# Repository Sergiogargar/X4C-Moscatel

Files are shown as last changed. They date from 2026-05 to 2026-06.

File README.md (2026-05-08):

# X4C-Moscatel — Firmware ESP32

Nodo IoT de borde para monitorización de infraestructura ferroviaria.  
Captura la firma vibratoria del tren mediante el IMU ICM-20948, la geolocaliza
con el GPS NEO-6M y publica los datos en tiempo real vía MQTT para alimentar
el dashboard de visualización.

---

## Puesta en marcha

### Requisitos previos

- [ESP-IDF](https://docs.espressif.com/projects/esp-idf/en/latest/esp32s3/get-started/) v5.x instalado y configurado
- Docker + Docker Compose (para el backend)
- El ESP32-S3 conectado por USB

---

### Paso 1 — Obtener la IP del host

El ESP32 publica los datos MQTT al host donde corre Docker.
Antes de compilar, averigua su IP (deben estar en la misma red WiFi):

```bash
# Windows
ipconfig

# Mac / Linux
ifconfig   # o: ip route get 1 | awk '{print $7}'
```

---

### Paso 2 — Configurar el firmware

Abre **`codeina/train_digital_twin/main/network_task.cpp`** y rellena las
macros al inicio del archivo:

```c
// ─── CONFIGURAR ANTES DE FLASHEAR ────────────────────────────────
#define WIFI_SSID       "NOMBRE_DE_TU_RED"        // ← SSID de tu red WiFi
#define WIFI_PASS       "CONTRASEÑA_DE_TU_RED"    // ← Contraseña WiFi
#define MQTT_BROKER_URI "mqtt://192.168.X.X:1883" // ← IP del host del paso 1
#define TRAIN_ID        "T-101"  // ← ID único por unidad (T-101, T-102, ...)
```

> Si tienes varios ESP32, cada uno debe tener un `TRAIN_ID` distinto.

---

### Paso 3 — Arrancar el backend Docker

```bash
cd codeina/train_digital_twin/backend
docker-compose up -d
```

Comprueba que los cuatro contenedores están corriendo:

```bash
docker-compose ps
```

| Servicio | Puerto | Descripción |
|---|---|---|
| Mosquitto | `1883` | Broker MQTT. Recibe los mensajes del ESP32 |
| InfluxDB 2.7 | `8086` | Base de datos. Panel en http://localhost:8086 (`admin` / `adminpassword`) |
| Telegraf | — | Lee el topic MQTT y escribe en InfluxDB |
| Grafana | `3000` | Visualización alternativa en http://localhost:3000 (`admin` / `admin`) |

---

### Paso 4 — Compilar y flashear

```bash
cd codeina/train_digital_twin
idf.py build
idf.py flash
idf.py monitor    # muestra logs serie para verificar conexión WiFi y MQTT
```

O en un solo comando:

```bash
idf.py build flash monitor
```

---

### Paso 5 — Verificar que los datos llegan

Con `idf.py monitor` activo, deberías ver en los logs:

```
I (xxxx) NETWORK_TASK: MQTT Conectado
I (xxxx) NETWORK_TASK: Inicializando Network Task en Core 0
```

Para confirmar que los datos llegan a InfluxDB, abre http://localhost:8086,
entra con `admin` / `adminpassword`, ve a **Data Explorer** y consulta el
bucket `vibrations`. Si hay filas, el pipeline completo funciona.

---

### Referencia rápida de configuración

| Qué cambiar | Archivo | Dónde |
|---|---|---|
| Red WiFi y contraseña | `main/network_task.cpp` | Macros `WIFI_SSID` / `WIFI_PASS` |
| IP del broker MQTT | `main/network_task.cpp` | Macro `MQTT_BROKER_URI` |
| ID del tren | `main/network_task.cpp` | Macro `TRAIN_ID` |
| Umbral de impacto crítico | `main/sensor_task.cpp` | Frecuencia de muestreo y ventana FFT |
| Coordenadas de simulación GPS | `main/telemetry_task.cpp` | Función `parse_nmea()` |

---

## Estructura del firmware

```
codeina/train_digital_twin/
├── main/
│   ├── main.cpp            # Punto de entrada: crea las 4 tareas FreeRTOS
│   ├── data_types.h        # Estructuras de datos compartidas entre tareas
│   ├── telemetry_task.cpp  # Core 0: lee GPS (UART) e IMU (I2C) a 100 Hz
│   ├── sensor_task.cpp     # Core 1: muestreo ADC 10 kHz + FFT 1024 muestras
│   ├── network_task.cpp    # Core 0: WiFi + MQTT → publica JSON al broker
│   └── sd_task.cpp         # Core 0: escribe registros binarios en MicroSD
└── backend/
    ├── docker-compose.yml  # Mosquitto + InfluxDB + Telegraf + Grafana
    ├── mosquitto/config/   # Config del broker MQTT (allow_anonymous)
    └── telegraf/           # telegraf.conf: suscribe MQTT → escribe InfluxDB
```

---

## Flujo de datos

```
ICM-20948 (IMU)  ──┐
                   ├──▶  sensor_task  ──▶  FFT (1024 muestras, 10 kHz)
NEO-6M (GPS)  ─────┘         │                       │
                              │                       ▼
                        telemetry_task         dominant_freq_hz
                              │                       │
                              └───────────────────────┘
                                          │
                                    ProcessedVibrationData_t
                                    (pool de memoria, zero-copy)
                                       ┌──┴──┐
                                       ▼     ▼
                                   SD Task  Network Task
                                   (.bin)       │
                                             MQTT JSON
                                                │
                                          Mosquitto :1883
                                                │
                                           Telegraf
                                                │
                                         InfluxDB :8086
                                                │
                                         Dashboard React
```

### Payload JSON publicado

Cada mensaje MQTT al topic `train/telemetry/vibrations` tiene esta forma:

```json
{
  "timestamp":        1746700000000,
  "lat":              36.6850,
  "lon":              -6.1261,
  "alt":              55.0,
  "accel_z":          10.15,
  "dominant_freq_hz": 42.5,
  "trainId":          "T-101"
}
```

El dashboard convierte `accel_z` (m/s²) a g con `|accel_z − 9.81| / 9.81`
y clasifica el punto como ok / warning / critical según los umbrales definidos en la UI.

---

## Descripción del proyecto

Este es un GEM de Gemini con información completa del proyecto:
https://gemini.google.com/gem/1v8jnuFOj4cJeROFavsBkOiZ2vt1CeKzN?usp=sharing

El proyecto consiste en un nodo **IoT de borde (Edge Computing)** diseñado para
la monitorización de la infraestructura ferroviaria. Su función es capturar la
"firma vibratoria" y la posición geográfica del tren en tiempo real para crear
un modelo digital (Gemelo Digital) que permita predecir fallos en la vía o en
el material rodante.

**Los 3 pilares del Gemelo Digital:**

- **El Objeto Físico:** El tren y la infraestructura (vías, catenarias).
- **El Modelo Virtual:** Representación matemática — modelos de fatiga de materiales, algoritmos de predicción.
- **La Conexión de Datos (aquí entramos nosotros):** El flujo constante de información desde los sensores (ESP32-S3) hacia el modelo virtual.

**Algoritmo en el ESP32-S3:**

1. **Adquisición** — Core 1 muestrea la IMU a 10 kHz. Core 0 lee GPS a 1 Hz y gestiona escritura en SD.
2. **Fusión de datos** — Cada trama FFT se vincula al último GPS conocido mediante mutex FreeRTOS.
3. **FFT** — Ventana Hann de 1024 muestras → 512 bins de frecuencia (resolución ~9.8 Hz/bin, rango 0–5 kHz).
4. **Frecuencia dominante** — Se extrae el bin de mayor energía (ignorando DC) y se envía como `dominant_freq_hz`.
5. **Escritura segura** — SD escribe en bloques cada 100 registros para evitar corrupción ante cortes de energía.

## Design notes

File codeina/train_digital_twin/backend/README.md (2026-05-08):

# Backend de Monitorización de Vías (Gemelo Digital)

Este directorio contiene la infraestructura para recibir, almacenar y visualizar la telemetría del ESP32-S3.

## Despliegue Rápido
Asegúrate de tener instalado **Docker** y **Docker Compose**.
1. En esta misma carpeta, ejecuta:
   ```bash
   docker-compose up -d
   ```
2. Esto levantará:
   - **Mosquitto (Broker MQTT)**: Puerto 1883
   - **InfluxDB (Base de datos Time-Series)**: Puerto 8086
   - **Telegraf (Agente)**: Conecta Mosquitto con InfluxDB.
   - **Grafana (Dashboards)**: Puerto 3000

## Credenciales por Defecto
- **InfluxDB**: `admin` / `adminpassword` (Token: `my-super-secret-auth-token`)
- **Grafana**: `admin` / `admin`

## Configuración en Grafana y Consultas (Flux)

Para visualizar los datos en un panel **Geomap** de Grafana y destacar puntos donde la vibración (ej. el pico en Z o frecuencias de la FFT) supera un umbral anómalo:

1. Añade InfluxDB como Data Source en Grafana. Selecciona el lenguaje **Flux**.
2. URL: `http://influxdb:8086`, Organization: `train_org`, Token: `my-super-secret-auth-token`, Default Bucket: `vibrations`.

### Query Flux para el Mapa (Anomalías)
Asumiendo que Telegraf inserta la latitud (`lat`), longitud (`lon`), y la aceleración en Z (`accel_z`), podemos filtrar las aceleraciones que representen impactos severos (ej. baches en la vía).

```flux
from(bucket: "vibrations")
  |> range(start: v.timeRangeStart, stop: v.timeRangeStop)
  |> filter(fn: (r) => r["_measurement"] == "mqtt_consumer")
  |> filter(fn: (r) => r["_field"] == "lat" or r["_field"] == "lon" or r["_field"] == "accel_z")
  |> pivot(rowKey:["_time"], columnKey: ["_field"], valueColumn: "_value")
  // Filtrar solo vibraciones anómalas (ejemplo: aceleración Z > 12.0 m/s^2)
  |> filter(fn: (r) => r["accel_z"] > 12.0)
  |> keep(columns: ["_time", "lat", "lon", "accel_z"])
```

En Grafana, en las opciones del panel **Geomap**:
- Location: `Coords`
- Latitude field: `lat`
- Longitude field: `lon`
- Puedes usar `accel_z` para determinar el tamaño o color del marcador (ej. un marcador rojo intenso para picos grandes).

### Analizando la FFT
El espectro FFT se envía como un array JSON. InfluxDB (vía Telegraf) guardará cada índice de frecuencia si se configura correctamente o si se envían como métricas separadas en el ESP32. Para visualización avanzada de la FFT, se recomienda un panel **Bar Gauge** o **Time Series** mostrando la magnitud de frecuencias clave (ej. frecuencia de resonancia de los bogies).

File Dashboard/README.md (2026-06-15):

# Xerez4Change — Dashboard

Dashboard de monitorización de vibraciones en vía férrea.  
Visualiza en tiempo real los puntos GPS enviados por el ESP32, con código de colores por nivel de vibración, filtros por fecha/tren/anomalía y diseño en modo oscuro.

---

## Configuración y arranque

### Requisitos previos

- Node.js ≥ 18
- El backend Docker arrancado (ver sección [Backend](#backend))

### 1. Instalar dependencias

```bash
cd Xerez4Change-Dashboard
npm install
```

### 2. Configurar la conexión a InfluxDB

Edita el archivo **`.env`** en la raíz del proyecto. Los valores por defecto
corresponden a la configuración estándar del `docker-compose` del backend:

```env
VITE_INFLUX_TOKEN=my-super-secret-auth-token
VITE_INFLUX_ORG=train_org
VITE_INFLUX_BUCKET=vibrations
VITE_POLL_INTERVAL_MS=10000
```

> En desarrollo, las peticiones a InfluxDB van a través del proxy de Vite
> (`/influx → http://localhost:8086`), por lo que no hace falta exponer la URL.  
> Para producción, añade `VITE_INFLUX_URL=http://<ip-servidor>:8086`.

### 3. Arrancar el servidor de desarrollo

```bash
npm run dev
```

El dashboard estará disponible en **http://localhost:5173**.

Si InfluxDB no está arrancado, el dashboard carga automáticamente datos de
demostración (mock) y muestra el indicador **"Simulado · Mock"** en la cabecera.
En cuanto el backend esté activo y con datos, cambia a **"En vivo · InfluxDB"**.

### 4. Compilar para producción

```bash
npm run build      # genera dist/
npm run preview    # sirve el build en http://localhost:4173
```

---

## Backend

El backend vive en `X4C-Moscatel/codeina/train_digital_twin/backend/`.

### 1. Averiguar la IP de tu máquina

El ESP32 necesita saber a qué IP conectarse. Antes de flashear, obtén la IP
del host donde vas a correr Docker y anótala:

```bash
# Windows
ipconfig
# Mac / Linux
ifconfig   # o: ip route get 1 | awk '{print $7}'
```

> El ESP32 y el host deben estar en la **misma red WiFi**.

### 2. Arrancar el backend Docker

```bash
cd X4C-Moscatel/codeina/train_digital_twin/backend
docker-compose up -d
```

Levanta cuatro servicios:

| Servicio | Puerto | Descripción |
|---|---|---|
| Mosquitto | `1883` | Broker MQTT. Recibe los mensajes del ESP32 |
| InfluxDB 2.7 | `8086` | Base de datos de series temporales. Panel en http://localhost:8086 (`admin` / `adminpassword`) |
| Telegraf | — | Suscribe el topic MQTT y escribe los campos en InfluxDB |
| Grafana | `3000` | Dashboard alternativo en http://localhost:3000 (`admin` / `admin`) |

Para verificar que los contenedores están corriendo:

```bash
docker-compose ps
```

### 3. Configurar y flashear el ESP32

Antes de flashear, edita **`X4C-Moscatel/codeina/train_digital_twin/main/network_task.cpp`**
y rellena las tres macros al inicio del archivo:

```c
#define WIFI_SSID       "NOMBRE_DE_TU_RED"        // ← tu red WiFi
#define WIFI_PASS       "CONTRASEÑA_DE_TU_RED"    // ← tu contraseña
#define MQTT_BROKER_URI "mqtt://192.168.X.X:1883" // ← IP del host del paso 1
#define TRAIN_ID        "T-101"                   // ← ID único por unidad
```

Luego compila y flashea con ESP-IDF:

```bash
cd X4C-Moscatel/codeina/train_digital_twin
idf.py build flash monitor
```

Una vez el ESP32 esté corriendo y con fix GPS, los puntos empezarán a
aparecer en el mapa con el indicador **"En vivo · InfluxDB"** en la cabecera.

---

## Cómo funciona

### Flujo completo de datos

```
ESP32 (WiFi + MQTT)
    │  topic: train/telemetry/vibrations
    ▼
Mosquitto :1883
    │
    ▼
Telegraf  →  aplana JSON  →  InfluxDB :8086
                                    │
                                    │  Flux query (cada 10 s)
                                    ▼
                            geoService.ts
                                    │  parseInfluxCSV()
                                    │  accel_z → vibration_g
                                    │  deriva anomalyType
                                    ▼
                            useGeoData.ts  →  dashboardStore.ts
                                                    │
                                    ┌───────────────┘
                                    │  filteredPoints
                                    ▼
                            GeoMap.tsx  →  CircleMarker por cada punto
```

### Lógica interna capa a capa

#### `src/services/geoService.ts` — Origen de datos

Es el único punto de entrada de datos al dashboard. Ejecuta una consulta Flux
sobre InfluxDB pidiendo las últimas 2 horas de mediciones, máximo 500 puntos:

```flux
from(bucket: "vibrations")
  |> range(start: -2h)
  |> filter(fn: (r) => r._measurement == "mqtt_consumer")
  |> pivot(rowKey:["_time"], columnKey: ["_field"], valueColumn: "_value")
  |> sort(columns: ["_time"], desc: false)
  |> limit(n: 500)
```

La respuesta es un CSV anotado (formato nativo de InfluxDB v2). El parser
interno lo convierte línea a línea en objetos `GeoPoint`:

- `lat`, `lon` → coordenadas directas
- `accel_z` (m/s²) → `vibration` en g: `|accel_z − 9.81| / 9.81`
- `trainId` → identificador del tren
- `_time` → timestamp ISO
- `dominant_freq_hz` → campo opcional si el ESP32 lo calcula y envía

Si InfluxDB no responde o devuelve datos vacíos, la función cae silenciosamente
a los datos mock y el indicador de cabecera cambia de verde a ámbar.
El módulo expone `getLastSource()` para que el hook sepa qué fuente se usó.

#### `src/utils/vibration.ts` — Clasificación y colores

Toda la lógica de semáforo está centralizada aquí. Los umbrales son:

| Vibración | Nivel | Color | Radio del marcador |
|---|---|---|---|
| < 0.3 g | `ok` | Verde `#10b981` | 6 px |
| 0.3 – 0.7 g | `warning` | Ámbar `#f59e0b` | 9 px |
| ≥ 0.7 g | `critical` | Rojo `#ef4444` | 12 px |

Para ajustar cuándo se considera crítico un punto, edita las constantes
`THRESHOLDS.warning` y `THRESHOLDS.critical` en este archivo.  
El campo `level` del tipo `GeoPoint` siempre se calcula aquí; los datos
de entrada no necesitan incluirlo.

#### `src/hooks/useGeoData.ts` — Ciclo de refresco

Al montarse, lanza la primera carga (con spinner) y arranca un `setInterval`
que refresca los datos cada `VITE_POLL_INTERVAL_MS` milisegundos (10 s por defecto).
Los refrescos periódicos son silenciosos: el mapa se actualiza sin parpadear.
Al desmontar el componente, cancela el intervalo y marca las peticiones en vuelo
como descartadas para evitar actualizar estado de componentes ya desmontados.

#### `src/store/dashboardStore.ts` — Estado global (Zustand)

Almacén central con dos listas de puntos:

- `points` — todos los puntos recibidos, sin filtrar
- `filteredPoints` — resultado de aplicar los filtros activos sobre `points`

Cada vez que llegan nuevos datos (`setPoints`) o cambia un filtro (`setFilters`),
`applyFilters()` recalcula `filteredPoints` en el mismo tick. El mapa solo
consume `filteredPoints`, por lo que nunca ve datos que no pasen los filtros.

Los tres filtros disponibles se evalúan en AND:

1. **Rango de fechas** — compara el `timestamp` ISO del punto con `[inicio, fin]`
2. **ID de tren** — coincidencia exacta de `trainId`
3. **Tipo de anomalía** — coincidencia exacta de `anomalyType`

#### `src/components/GeoMap.tsx` — Visualización

Componente puramente visual. Recibe `data: GeoPoint[]` y no sabe de dónde vienen.
Renderiza sobre un `MapContainer` de Leaflet centrado en la zona Jerez–Cádiz
(`[36.62, −6.20]`, zoom 12) con capa CartoDB Dark Matter.

Por cada punto crea un `CircleMarker` cuyo color y radio vienen de
`getVibrationColor()` y `getMarkerRadius()` de `vibration.ts`. Los puntos
críticos tienen borde de 2 px en lugar de 1 px para destacar más.

Cada marcador tiene:
- **Tooltip** (hover): tren + vibración, aparece rápido
- **Popup** (click): detalle completo — nivel, tren, vibración, frecuencia dominante (si existe), tipo de anomalía (si existe) y timestamp formateado

Dos overlays posicionados con `z-index: 1000` sobre el mapa:
- **`Legend`** — abajo a la izquierda, muestra los tres colores con sus rangos
- **`Stats`** — arriba a la derecha, muestra total de puntos, avisos y críticos

#### `src/components/FilterBar.tsx` — Filtros

Los desplegables de tren y anomalía se alimentan de `fetchTrainIds()` y
`fetchAnomalyTypes()`, que derivan los valores únicos de los propios datos.
Cualquier filtro que se active llama a `setFilters()` del store, lo que
recalcula `filteredPoints` al instante sin ninguna petición de red adicional.

---

## Estructura de archivos

```
src/
├── components/
│   ├── GeoMap.tsx          # Mapa Leaflet: marcadores, leyenda, stats
│   └── FilterBar.tsx       # Filtros de fecha, tren y anomalía
├── hooks/
│   └── useGeoData.ts       # Polling + carga inicial + fuente activa
├── services/
│   └── geoService.ts       # Flux query → parse CSV → GeoPoint[] (fallback mock)
├── store/
│   └── dashboardStore.ts   # Zustand: puntos, filtros, loading, error
├── utils/
│   └── vibration.ts        # Umbrales, colores, radios, formateo
├── types.ts                # GeoPoint, DashboardFilters, VibrationLevel
├── App.tsx                 # Layout: cabecera + badge de estado + mapa
├── main.tsx                # Punto de entrada de React
└── index.css               # Tailwind + estilos oscuros para popups de Leaflet
```

---

## Referencia rápida

| Necesidad | Dónde |
|---|---|
| Cambiar token / org / bucket de InfluxDB | `.env` |
| Cambiar intervalo de refresco | `.env` → `VITE_POLL_INTERVAL_MS` |
| Cambiar IP de InfluxDB en producción | `.env` → `VITE_INFLUX_URL` |
| Ajustar umbrales de vibración | `src/utils/vibration.ts` → `THRESHOLDS` |
| Cambiar ventana de tiempo de la query | `src/services/geoService.ts` → `range(start: -2h)` |
| Cambiar centro o zoom inicial del mapa | `src/components/GeoMap.tsx` → `DEFAULT_CENTER`, `DEFAULT_ZOOM` |
| Añadir un filtro nuevo | `src/types.ts` + `src/store/dashboardStore.ts` + `src/components/FilterBar.tsx` |

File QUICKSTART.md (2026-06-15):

# Guía de inicio rápido — X4C Moscatel

## Requisitos

| Herramienta | Versión mínima |
|---|---|
| ESP-IDF | v5.x |
| Docker + Docker Compose | cualquiera |
| Node.js | v18+ |
| Git | cualquiera |

---

## 1. Configurar el firmware

Abre `codeina/train_digital_twin/main/network_task.cpp` y edita las 4 macros al inicio:

```c
#define WIFI_SSID       "MI_RED_WIFI"
#define WIFI_PASS       "MI_CONTRASEÑA"
#define MQTT_BROKER_URI "mqtt://192.168.X.X:1883"   // IP del PC donde corre Docker
#define TRAIN_ID        "T-101"
```

Para saber la IP del PC: `ipconfig` (Windows) o `ip a` (Linux/Mac).

---

## 2. Arrancar el backend Docker

```bash
cd codeina/train_digital_twin/backend
docker-compose up -d
```

Comprueba que los 4 contenedores están en "Up":

```bash
docker-compose ps
```

| Servicio | URL | Credenciales |
|---|---|---|
| InfluxDB | http://localhost:8086 | admin / adminpassword |
| Grafana | http://localhost:3000 | admin / admin |
| Mosquitto (MQTT) | localhost:1883 | sin autenticación |
| Telegraf | — | puente interno |

---

## 3. Flashear el ESP32

```bash
cd codeina/train_digital_twin
idf.py build flash monitor
```

En el monitor serie deberías ver:

```
I (xxx) MAIN: Iniciando Gemelo Digital de Tren
I (xxx) NETWORK_TASK: WiFi conectado. IP asignada: 192.168.X.X
I (xxx) NETWORK_TASK: MQTT Conectado
I (xxx) SENSOR_TASK: Dato Crudo Z: X.XX m/s2 | Freq Dominante: XX.XX Hz
```

---

## 4. Arrancar el dashboard

```bash
cd Dashboard
npm install
npm run dev
```

Abre http://localhost:5173

- Indicador **verde "En vivo · InfluxDB"** → datos reales del ESP32
- Indicador **ámbar "Simulado · Mock"** → InfluxDB no accesible (revisa paso 2)

---

## Verificar que el pipeline completo funciona

### A. InfluxDB recibe datos
1. Entra en http://localhost:8086 → `admin / adminpassword`
2. Ve a **Data Explorer** → bucket `vibrations`
3. Selecciona measurement `mqtt_consumer` → deberías ver campos: `lat`, `lon`, `accel_z`, `dominant_freq_hz`

### B. Dashboard muestra datos en el mapa
- Los marcadores aparecen en la zona Jerez–Cádiz (lat ~36.6, lon ~-6.1)
- **Verde** = vibración < 0.3 g (normal)
- **Ámbar** = vibración 0.3–0.7 g (aviso)
- **Rojo** = vibración > 0.7 g (crítico)
- Haz clic en un marcador para ver: tren, vibración, frecuencia dominante, timestamp

### C. MQTT llega al broker
```bash
# Instalar mosquitto-clients si no lo tienes
docker exec mqtt_broker mosquitto_sub -t "train/telemetry/vibrations" -v
```
Deberías ver mensajes JSON como:
```json
{"timestamp":1234567890000,"lat":36.685,"lon":-6.126,"accel_z":9.95,"dominant_freq_hz":42.5,"trainId":"T-101"}
```

---

## Formato del payload MQTT

El ESP32 publica en el topic `train/telemetry/vibrations`:

```json
{
  "timestamp":        1746700000000,
  "lat":              36.6850,
  "lon":             -6.1261,
  "alt":              55.0,
  "accel_z":          9.95,
  "dominant_freq_hz": 42.5,
  "vibration_amp":    -12.3,
  "trainId":          "T-101"
}
```

El dashboard convierte `accel_z` (m/s²) a g con `|accel_z − 9.81| / 9.81`.

> **Nota:** El ESP32 descarta automáticamente los puntos sin fix GPS para no publicar coordenadas (0, 0).

---

## Parar todo

```bash
# Backend
cd codeina/train_digital_twin/backend
docker-compose down

# Dashboard: Ctrl+C en la terminal
```

---

## Problemas frecuentes

| Síntoma | Causa probable | Solución |
|---|---|---|
| Dashboard en modo mock (ámbar) | Backend no arrancado o InfluxDB sin datos | Ejecutar paso 2, esperar 30 s y recargar |
| Monitor serie: `Conexion WiFi fallida` | SSID/contraseña incorrectos | Revisar macros en `network_task.cpp` y reflashear |
| Monitor serie: `GPS sin fix` | Módulo GPS sin señal (normal en interiores) | Llevar el dispositivo al exterior; los datos no se publican hasta obtener fix |
| `docker-compose ps` muestra contenedores en "Exit" | Puerto 8086 o 1883 ocupado por otra app | `docker-compose logs <servicio>` para ver el error |
| Mapa vacío pese a datos en InfluxDB | El query Flux filtra `-2h`; datos más antiguos no aparecen | Comprobar que el reloj del ESP32 y el host están sincronizados |

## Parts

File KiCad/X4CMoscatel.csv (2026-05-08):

Reference | Qty | Value | DNP | Exclude from BOM | Exclude from Board | Footprint | Datasheet
C1,C3,C4,C5 | 4 | 100nF |  |  |  | Capacitor_SMD:C_0805_2012Metric | ~
C2 | 1 | 10microF |  |  |  | Capacitor_SMD:C_0805_2012Metric | ~
D1 | 1 | D_Schottky |  |  |  | Diode_SMD:D_SMA | ~
D2,D3 | 2 | LED |  |  |  | LED_SMD:LED_0805_2012Metric | ~
D4 | 1 | BAT54S |  |  |  | Package_TO_SOT_SMD:SOT-23 | https://www.diodes.com/assets/Datasheets/ds11005.pdf
H1,H3,H4 | 3 | MountingHole |  | Excluido del BOM |  | MountingHole:MountingHole_3.2mm_M3 | ~
J1 | 1 | Conn_01x04 |  |  |  | Connector_PinHeader_2.54mm:PinHeader_1x04_P2.54mm_Vertical | ~
J2 | 1 | Micro_SD_Card_Det_Hirose_DM3AT |  |  |  | Connector_Card:microSD_HC_Molex_104031-0811 | https://www.hirose.com/product/en/download_file/key_name/DM3/category/Catalog/doc_file_id/49662/?item_id=195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
J3 | 1 | USB_C_Receptacle_USB2.0_14P |  |  |  | Connector_USB:USB_C_Receptacle_HRO_TYPE-C-31-M-12 | https://www.usb.org/sites/default/files/documents/usb_type-c.zip
J4 | 1 | Conn_01x02_Pin |  |  |  | Connector_JST:JST_PH_S2B-PH-K_1x02_P2.00mm_Horizontal | ~
J5 | 1 | Conn_01x10_Pin |  |  |  | Connector_PinHeader_2.54mm:PinHeader_1x10_P2.54mm_Vertical | ~
J6 | 1 | Conn_01x02_Pin |  |  |  | Connector_PinSocket_2.54mm:PinSocket_1x02_P2.54mm_Vertical | ~
R1,R3 | 2 | 10k |  |  |  | Resistor_SMD:R_0805_2012Metric | ~
R2,R7 | 2 | 5.1k |  |  |  | Resistor_SMD:R_0805_2012Metric | ~
R4 | 1 | 2k |  |  |  | Resistor_SMD:R_0805_2012Metric | ~
R5,R6 | 2 | 1k |  |  |  | Resistor_SMD:R_0805_2012Metric | ~
R8,R9,R10 | 3 | 1M |  |  |  | Resistor_SMD:R_0805_2012Metric | ~
SW1,SW2 | 2 | SW_Push |  |  |  | Button_Switch_SMD:SW_Push_SPST_NO_Alps_SKRK | ~
SW3 | 1 | SW_Wuerth_450301014042 |  |  |  | Button_Switch_THT:SW_Slide-03_Wuerth-WS-SLTV_10x2.5x6.4_P2.54mm | https://www.we-online.com/components/products/datasheet/450301014042.pdf
U1 | 1 | ESP32-S3-WROOM-1 |  |  |  | RF_Module:ESP32-S3-WROOM-1 | https://www.espressif.com/sites/default/files/documentation/esp32-s3-wroom-1_wroom-1u_datasheet_en.pdf
U2 | 1 | MCP6002-xMC |  |  |  | Package_DFN_QFN:DFN-8-1EP_3x2mm_P0.5mm_EP1.75x1.45mm | http://ww1.microchip.com/downloads/en/DeviceDoc/21733j.pdf
U3 | 1 | LD1117V33 |  |  |  | Package_TO_SOT_THT:TO-220-3_Vertical | https://www.st.com/resource/en/datasheet/ld1117.pdf
U4 | 1 | MCP73831-2-OT |  |  |  | Package_TO_SOT_SMD:SOT-23-5 | http://ww1.microchip.com/downloads/en/DeviceDoc/20001984g.pdf

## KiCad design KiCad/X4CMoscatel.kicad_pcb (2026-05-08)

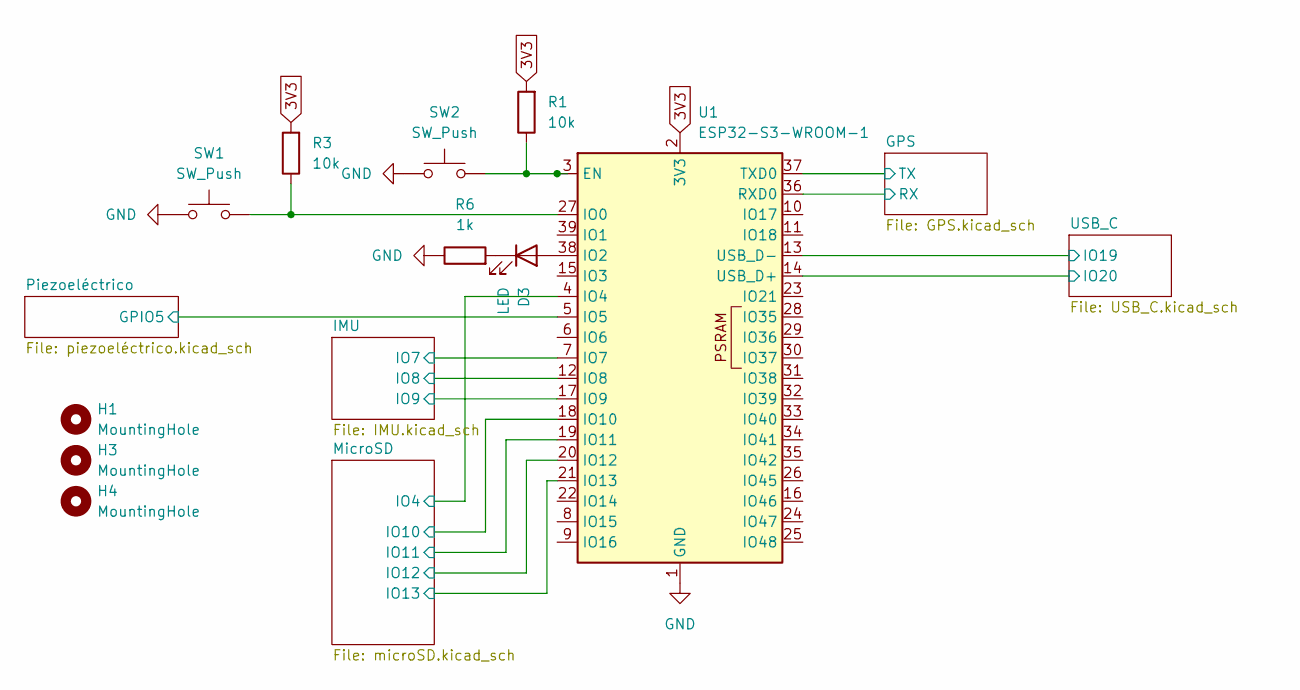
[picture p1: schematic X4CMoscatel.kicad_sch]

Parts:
D3: LED; LED_0805_2012Metric
H1, H3, H4: MountingHole; MountingHole_3.2mm_M3
R1, R3: 10k; R_0805_2012Metric
R6: 1k; R_0805_2012Metric
SW1, SW2: SW_Push; SW_Push_SPST_NO_Alps_SKRK
U1: ESP32-S3-WROOM-1

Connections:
3V3: R1.2, R3.2, U1.2 (3V3); also elsewhere on the board
/GPS/RX: U1.36 (RXD0); also elsewhere on the board
/GPS/TX: U1.37 (TXD0); also elsewhere on the board
/IMU/IO7: U1.7 (IO7); also elsewhere on the board
/IMU/IO8: U1.12 (IO8); also elsewhere on the board
/IMU/IO9: U1.17 (IO9); also elsewhere on the board
/MicroSD/IO4: U1.4 (IO4); also elsewhere on the board
/MicroSD/IO10: U1.18 (IO10); also elsewhere on the board
/MicroSD/IO11: U1.19 (IO11); also elsewhere on the board
/MicroSD/IO12: U1.20 (IO12); also elsewhere on the board
/MicroSD/IO13: U1.21 (IO13); also elsewhere on the board
/Piezoeléctrico/GPIO5: U1.5 (IO5); also elsewhere on the board
/USB_C/IO19: U1.13 (USB_D-); also elsewhere on the board
/USB_C/IO20: U1.14 (USB_D+); also elsewhere on the board
GND: R6.1, SW1.1, SW2.1, U1.1 (GND), U1.40 (GND), U1.41 (GND); also elsewhere on the board
unnamed: D3.2 (A), U1.38 (IO2)
unnamed: D3.1 (K), R6.2
unnamed: R1.1, SW2.2, U1.3 (EN)
unnamed: R3.1, SW1.2, U1.27 (IO0)

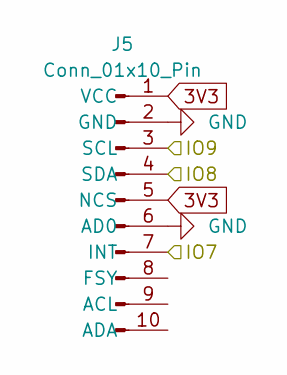
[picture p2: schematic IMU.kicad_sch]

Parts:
J5: Conn_01x10_Pin; PinHeader_1x10_P2.54mm_Vertical

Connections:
3V3: J5.1 (VCC), J5.5 (NCS); also elsewhere on the board
/IMU/IO7: J5.7 (INT); also elsewhere on the board
/IMU/IO8: J5.4 (SDA); also elsewhere on the board
/IMU/IO9: J5.3 (SCL); also elsewhere on the board
GND: J5.2 (GND), J5.6 (AD0); also elsewhere on the board

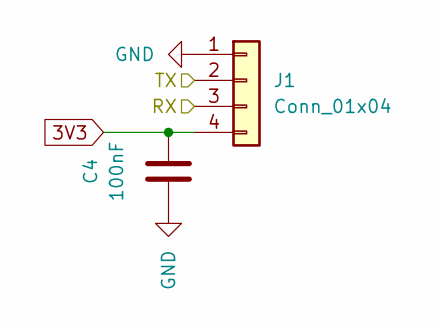
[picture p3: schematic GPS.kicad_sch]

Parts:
C4: 100nF; C_0805_2012Metric
J1: Conn_01x04; PinHeader_1x04_P2.54mm_Vertical

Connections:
3V3: C4.2, J1.4; also elsewhere on the board
/GPS/RX: J1.3; also elsewhere on the board
/GPS/TX: J1.2; also elsewhere on the board
GND: C4.1, J1.1; also elsewhere on the board

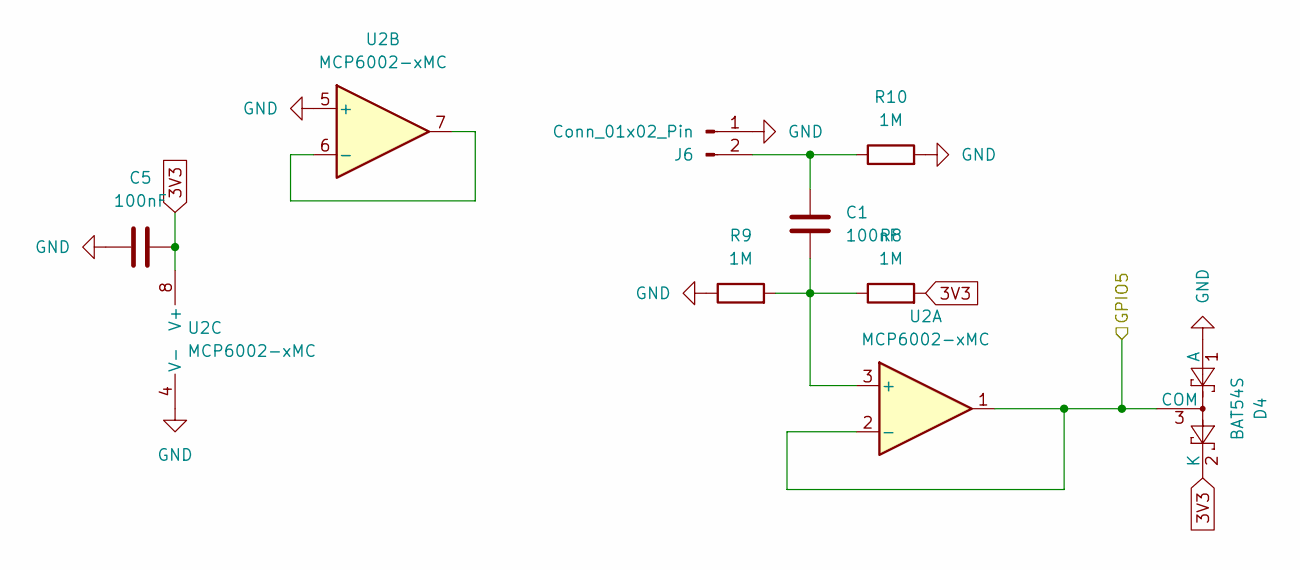
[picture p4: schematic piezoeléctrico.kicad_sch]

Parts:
C1, C5: 100nF; C_0805_2012Metric
D4: BAT54S; SOT-23
J6: Conn_01x02_Pin; PinSocket_1x02_P2.54mm_Vertical
R8, R9, R10: 1M; R_0805_2012Metric
U2: MCP6002-xMC; DFN-8-1EP_3x2mm_P0.5mm_EP1.75x1.45mm

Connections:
3V3: C5.1, D4.2 (K), R8.2, U2.8 (V+); also elsewhere on the board
/Piezoeléctrico/GPIO5: D4.3 (COM), U2.1, U2.2 (-); also elsewhere on the board
GND: C5.2, D4.1 (A), J6.1, R9.1, R10.2, U2.4 (V-), U2.5 (+), U2.9 (V-); also elsewhere on the board
unnamed: C1.2, J6.2, R10.1
unnamed: C1.1, R8.1, R9.2, U2.3 (+)
unnamed: U2.6 (-), U2.7

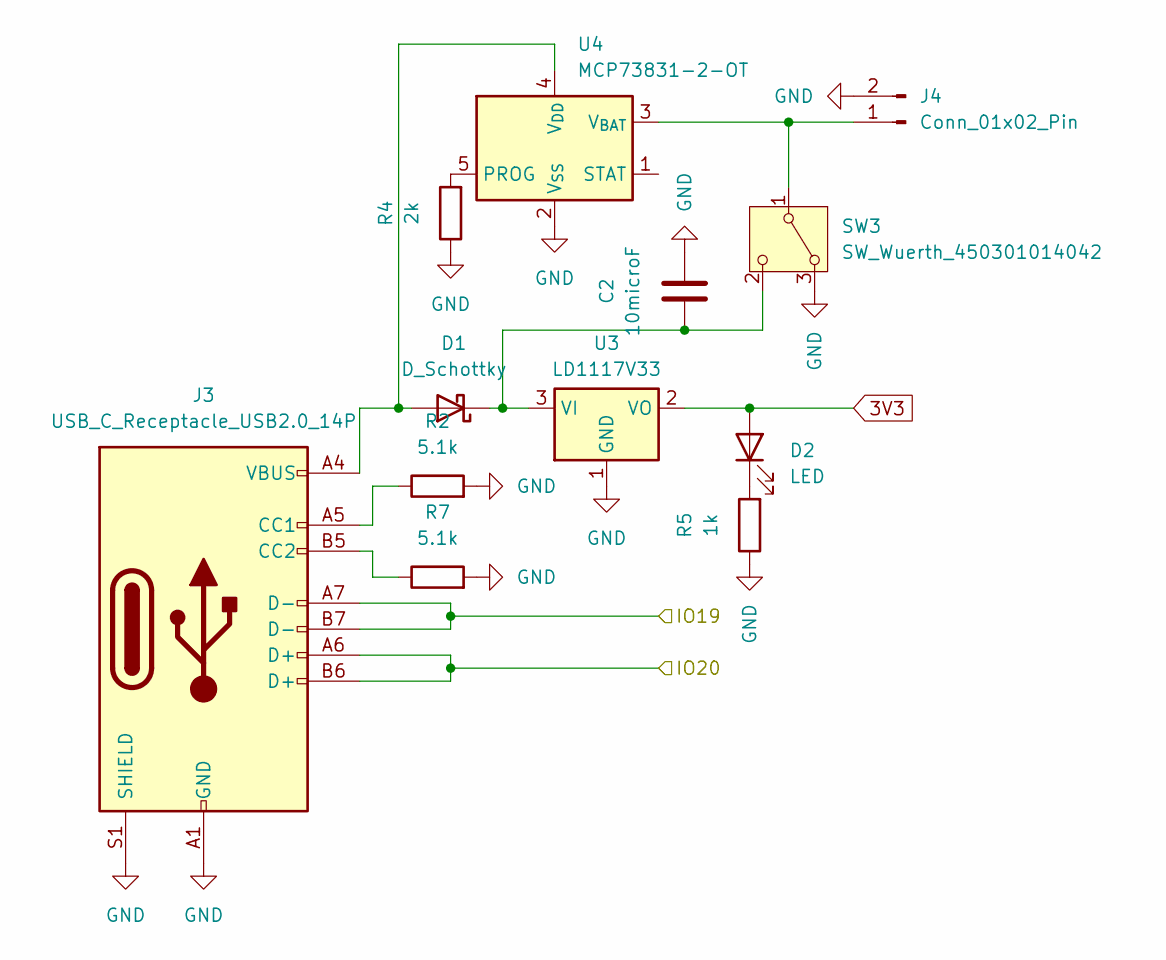
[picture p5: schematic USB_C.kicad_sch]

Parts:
C2: 10microF; C_0805_2012Metric
D1: D_Schottky; D_SMA
D2: LED; LED_0805_2012Metric
J3: USB_C_Receptacle_USB2.0_14P; USB_C_Receptacle_HRO_TYPE-C-31-M-12
J4: Conn_01x02_Pin; JST_PH_S2B-PH-K_1x02_P2.00mm_Horizontal
R2, R7: 5.1k; R_0805_2012Metric
R4: 2k; R_0805_2012Metric
R5: 1k; R_0805_2012Metric
SW3: SW_Wuerth_450301014042; SW_Slide-03_Wuerth-WS-SLTV_10x2.5x6.4_P2.54mm
U3: LD1117V33; TO-220-3_Vertical
U4: MCP73831-2-OT; SOT-23-5

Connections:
3V3: D2.2 (A), U3.2 (VO); also elsewhere on the board
/USB_C/IO19: J3.A7 (D-), J3.B7 (D-); also elsewhere on the board
/USB_C/IO20: J3.A6 (D+), J3.B6 (D+); also elsewhere on the board
GND: C2.2, J3.A1 (GND), J3.A12 (GND), J3.B1 (GND), J3.B12 (GND), J3.S1 (SHIELD), J4.2, R2.2, R4.1, R5.1, R7.2, SW3.3 (A), U3.1 (GND), U4.2 (V_{SS}); also elsewhere on the board
unnamed: D1.2 (A), J3.A4 (VBUS), J3.A9 (VBUS), J3.B4 (VBUS), J3.B9 (VBUS), U4.4 (V_{DD})
unnamed: C2.1, D1.1 (K), SW3.2 (C), U3.3 (VI)
unnamed: D2.1 (K), R5.2
unnamed: J3.A5 (CC1), R2.1
unnamed: J3.B5 (CC2), R7.1
unnamed: J4.1, SW3.1 (B), U4.3 (V_{BAT})
unnamed: R4.2, U4.5 (PROG)

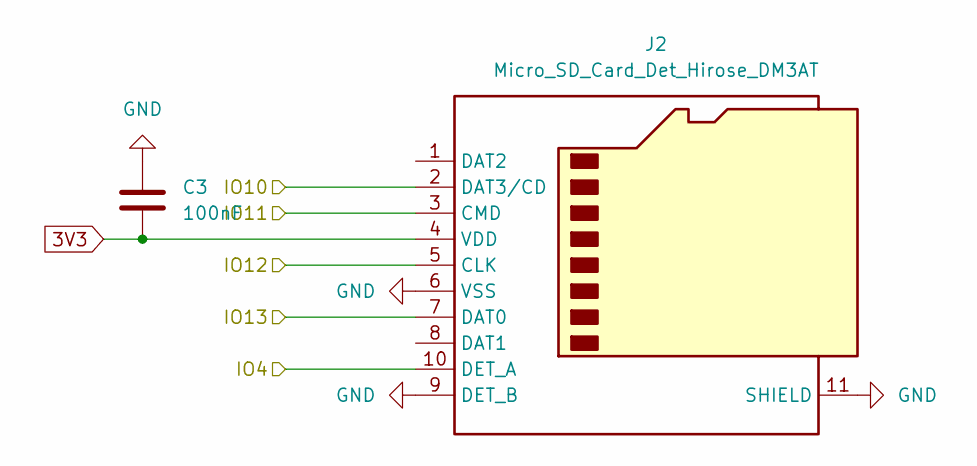
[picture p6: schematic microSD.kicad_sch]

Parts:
C3: 100nF; C_0805_2012Metric
J2: Micro_SD_Card_Det_Hirose_DM3AT; microSD_HC_Molex_104031-0811

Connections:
3V3: C3.1, J2.4 (VDD); also elsewhere on the board
/MicroSD/IO4: J2.10 (DET_A); also elsewhere on the board
/MicroSD/IO10: J2.2 (DAT3/CD); also elsewhere on the board
/MicroSD/IO11: J2.3 (CMD); also elsewhere on the board
/MicroSD/IO12: J2.5 (CLK); also elsewhere on the board
/MicroSD/IO13: J2.7 (DAT0); also elsewhere on the board
GND: C3.2, J2.6 (VSS), J2.9 (DET_B), J2.11 (SHIELD); also elsewhere on the board

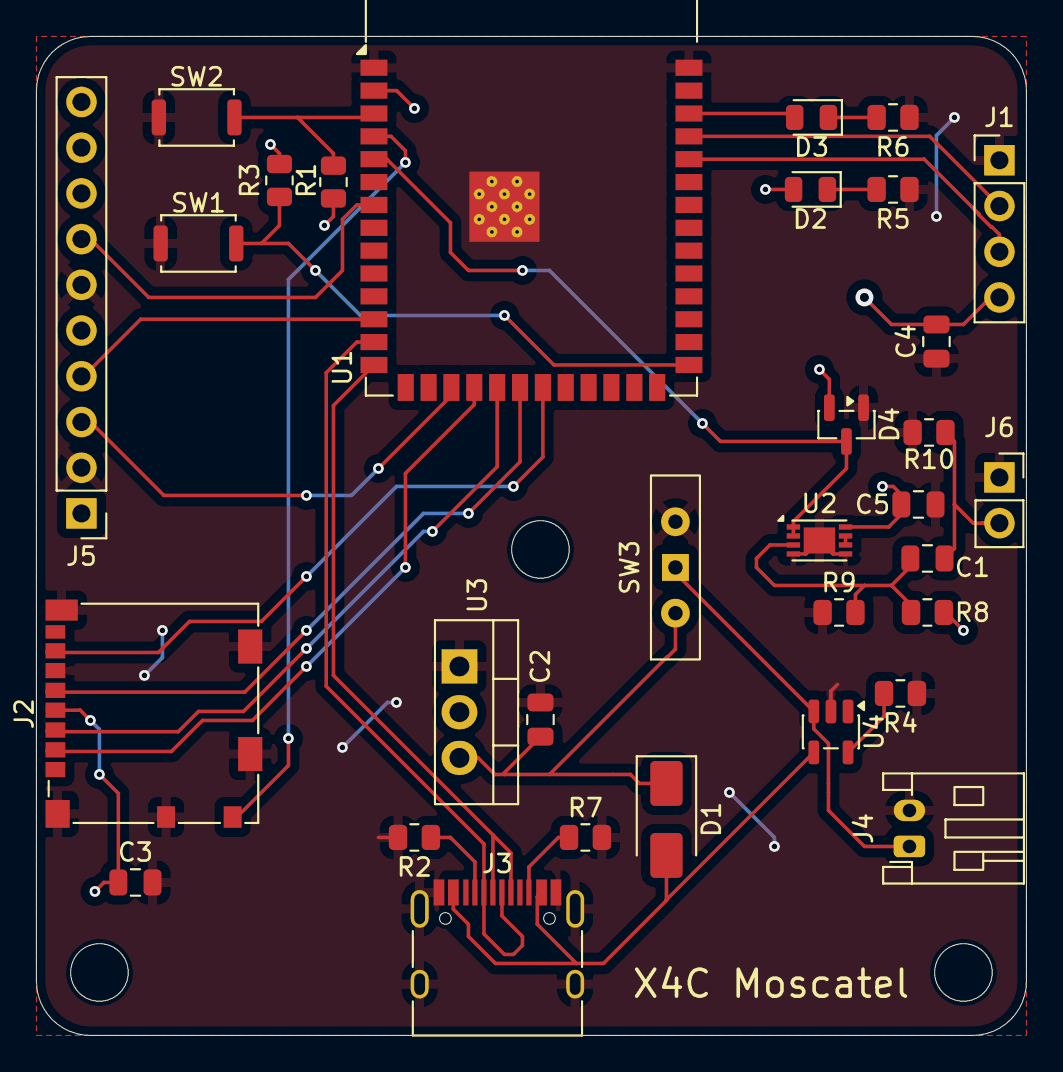
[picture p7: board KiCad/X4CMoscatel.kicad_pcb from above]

Board: 2 copper layers, 55.0 x 55.5 mm, 35 parts (0 on the bottom side), 29 nets.

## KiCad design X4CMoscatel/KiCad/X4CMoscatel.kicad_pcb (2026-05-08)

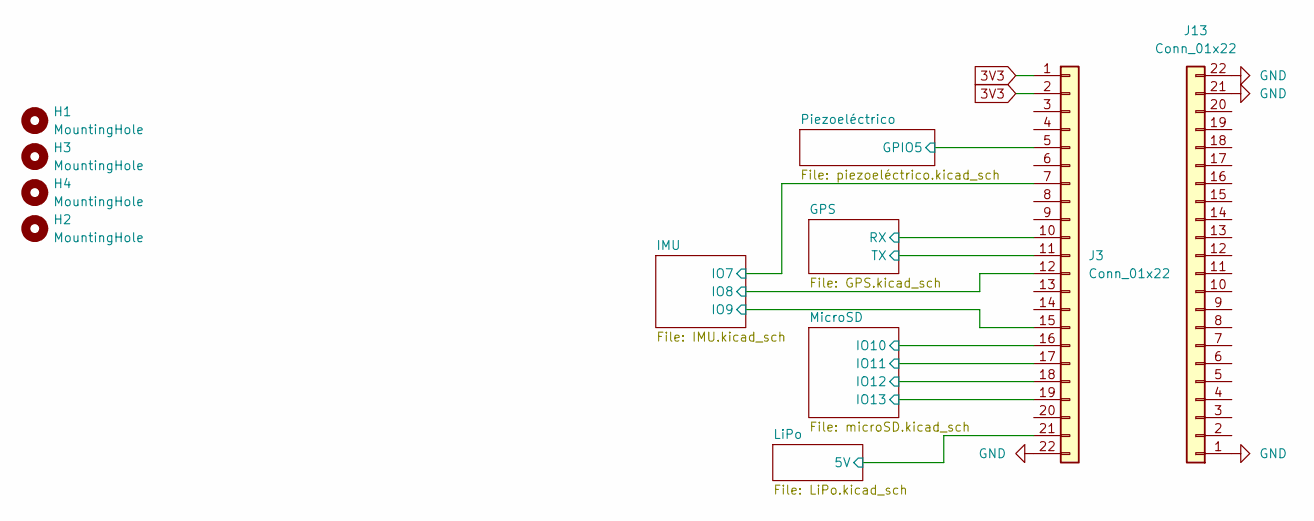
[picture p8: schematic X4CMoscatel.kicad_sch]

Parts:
H1, H2, H3, H4: MountingHole; MountingHole_3.2mm_M3
J3, J13: Conn_01x22; PinSocket_1x22_P2.54mm_Vertical

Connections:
3V3: J3.1, J3.2; also elsewhere on the board
/GPS/RX: J3.10; also elsewhere on the board
/GPS/TX: J3.11; also elsewhere on the board
/IMU/IO7: J3.7; also elsewhere on the board
/IMU/IO8: J3.12; also elsewhere on the board
/IMU/IO9: J3.15; also elsewhere on the board
/LiPo/5V: J3.21; also elsewhere on the board
/MicroSD/IO10: J3.16; also elsewhere on the board
/MicroSD/IO11: J3.17; also elsewhere on the board
/MicroSD/IO12: J3.18; also elsewhere on the board
/MicroSD/IO13: J3.19; also elsewhere on the board
/Piezoeléctrico/GPIO5: J3.5; also elsewhere on the board
GND: J3.22, J13.1, J13.21, J13.22; also elsewhere on the board

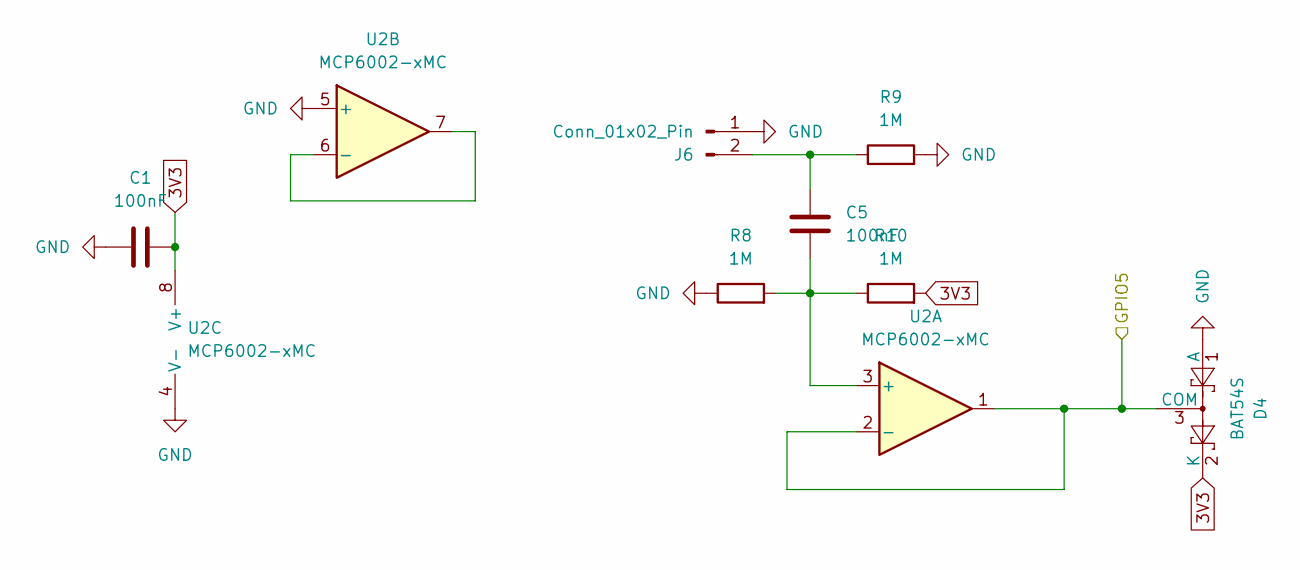
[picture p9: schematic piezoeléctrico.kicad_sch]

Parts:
C1, C5: 100nF; C_0805_2012Metric
D4: BAT54S; SOT-23
J6: Conn_01x02_Pin; PinSocket_1x02_P2.54mm_Vertical
R8, R9, R10: 1M; R_0805_2012Metric
U2: MCP6002-xMC; DFN-8-1EP_3x2mm_P0.5mm_EP1.75x1.45mm

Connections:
3V3: C1.1, D4.2 (K), R10.2, U2.8 (V+); also elsewhere on the board
/Piezoeléctrico/GPIO5: D4.3 (COM), U2.1, U2.2 (-); also elsewhere on the board
GND: C1.2, D4.1 (A), J6.1, R8.1, R9.2, U2.4 (V-), U2.5 (+), U2.9 (V-); also elsewhere on the board
unnamed: C5.2, J6.2, R9.1
unnamed: C5.1, R8.2, R10.1, U2.3 (+)
unnamed: U2.6 (-), U2.7

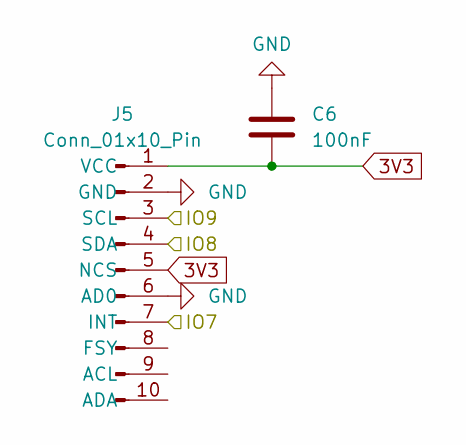
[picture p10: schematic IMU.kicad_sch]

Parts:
C6: 100nF; C_0805_2012Metric
J5: Conn_01x10_Pin; PinHeader_1x10_P2.54mm_Vertical

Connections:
3V3: C6.1, J5.1 (VCC), J5.5 (NCS); also elsewhere on the board
/IMU/IO7: J5.7 (INT); also elsewhere on the board
/IMU/IO8: J5.4 (SDA); also elsewhere on the board
/IMU/IO9: J5.3 (SCL); also elsewhere on the board
GND: C6.2, J5.2 (GND), J5.6 (AD0); also elsewhere on the board


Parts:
C4: 100nF; C_0805_2012Metric
J1: Conn_01x04; PinHeader_1x04_P2.54mm_Vertical

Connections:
3V3: C4.2, J1.4; also elsewhere on the board
/GPS/RX: J1.3; also elsewhere on the board
/GPS/TX: J1.2; also elsewhere on the board
GND: C4.1, J1.1; also elsewhere on the board

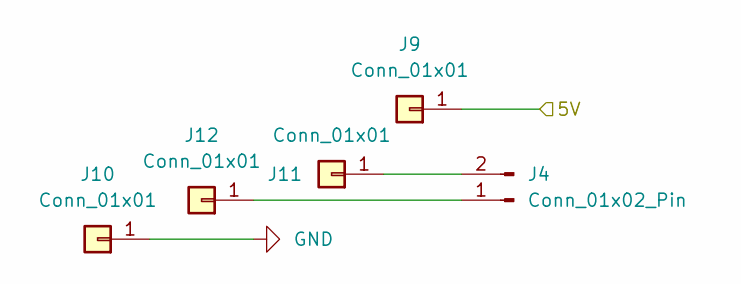
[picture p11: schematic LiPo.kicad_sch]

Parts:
J4: Conn_01x02_Pin; JST_PH_S2B-PH-K_1x02_P2.00mm_Horizontal
J9, J10, J11, J12: Conn_01x01; PinHeader_1x01_P2.54mm_Vertical

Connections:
/LiPo/5V: J9.1; also elsewhere on the board
GND: J10.1; also elsewhere on the board
unnamed: J4.2, J11.1
unnamed: J4.1, J12.1

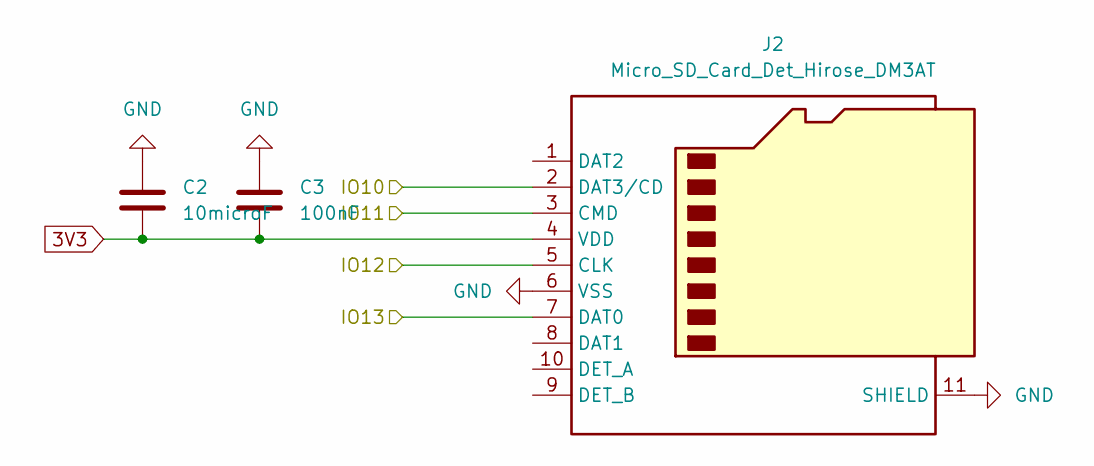
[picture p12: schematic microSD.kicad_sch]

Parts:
C2: 10microF; C_0805_2012Metric
C3: 100nF; C_0805_2012Metric
J2: Micro_SD_Card_Det_Hirose_DM3AT; microSD_HC_Molex_104031-0811

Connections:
3V3: C2.1, C3.1, J2.4 (VDD); also elsewhere on the board
/MicroSD/IO10: J2.2 (DAT3/CD); also elsewhere on the board
/MicroSD/IO11: J2.3 (CMD); also elsewhere on the board
/MicroSD/IO12: J2.5 (CLK); also elsewhere on the board
/MicroSD/IO13: J2.7 (DAT0); also elsewhere on the board
GND: C2.2, C3.2, J2.6 (VSS), J2.11 (SHIELD); also elsewhere on the board


Board: 2 copper layers, 60.0 x 75.0 mm, 26 parts (0 on the bottom side), 18 nets.

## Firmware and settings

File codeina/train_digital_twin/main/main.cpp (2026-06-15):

#include "freertos/FreeRTOS.h"
#include "freertos/task.h"
#include "freertos/queue.h"
#include "freertos/semphr.h"
#include "data_types.h"
#include "sensor_task.h"
#include "telemetry_task.h"
#include "sd_task.h"
#include "network_task.h"
#include "esp_log.h"
#include "nvs_flash.h"
#include "esp_netif.h"
#include "esp_event.h"
#include <stdlib.h>
#include <string.h>

static const char *TAG = "MAIN";

// Definición de variables globales
SemaphoreHandle_t xTelemetryMutex;
TelemetryData_t currentTelemetry;

QueueHandle_t xSdQueue;
QueueHandle_t xNetworkQueue;
QueueHandle_t xVibrationDataPool;

#define MEMORY_POOL_SIZE 10

extern "C" void app_main() {
    ESP_LOGI(TAG, "Iniciando Gemelo Digital de Tren (Vibraciones)");

    // 1. Inicializar NVS (requerido para WiFi)
    esp_err_t nvs_ret = nvs_flash_init();
    if (nvs_ret == ESP_ERR_NVS_NO_FREE_PAGES || nvs_ret == ESP_ERR_NVS_NEW_VERSION_FOUND) {
        ESP_ERROR_CHECK(nvs_flash_erase());
        nvs_ret = nvs_flash_init();
    }
    ESP_ERROR_CHECK(nvs_ret);

    // 2. Inicializar stack TCP/IP y bucle de eventos (requerido para WiFi)
    ESP_ERROR_CHECK(esp_netif_init());
    ESP_ERROR_CHECK(esp_event_loop_create_default());

    // 3. Conectar WiFi antes de crear las tareas
    bool wifi_ok = wifi_init_sta();
    if (!wifi_ok) {
        ESP_LOGW(TAG, "Sin conexion WiFi: el sistema arranca en modo offline (solo SD).");
    }

    // 4. Inicializar Primitivas de Sincronización
    memset(&currentTelemetry, 0, sizeof(currentTelemetry));
    xTelemetryMutex = xSemaphoreCreateMutex();

    xVibrationDataPool = xQueueCreate(MEMORY_POOL_SIZE, sizeof(ProcessedVibrationData_t*));
    xSdQueue      = xQueueCreate(MEMORY_POOL_SIZE, sizeof(VibrationMessage_t));
    xNetworkQueue = xQueueCreate(MEMORY_POOL_SIZE, sizeof(VibrationMessage_t));

    if (xVibrationDataPool == NULL || xSdQueue == NULL || xNetworkQueue == NULL || xTelemetryMutex == NULL) {
        ESP_LOGE(TAG, "Fallo al crear colas o semáforos. Memoria insuficiente.");
        return;
    }

    // 5. Pre-alojar memoria para el Memory Pool
    for (int i = 0; i < MEMORY_POOL_SIZE; i++) {
        ProcessedVibrationData_t *pData = (ProcessedVibrationData_t *)malloc(sizeof(ProcessedVibrationData_t));
        if (pData != NULL) {
            pData->ref_count = 0;
            xQueueSend(xVibrationDataPool, &pData, portMAX_DELAY);
        } else {
            ESP_LOGE(TAG, "Fallo al alocar memoria para el pool");
            return;
        }
    }

    // 6. Crear Tareas y asignarlas a los Cores adecuados (Core Pinning)

    // Core 0: Red, I/O, Telemetría
    xTaskCreatePinnedToCore(vTelemetryTask, "TelemetryTask", 4096, NULL, 1, NULL, 0);
    xTaskCreatePinnedToCore(vSdTask,        "SdTask",        4096, NULL, 2, NULL, 0);

    // wifi_ok se pasa a NetworkTask para que sepa si MQTT está disponible
    xTaskCreatePinnedToCore(vNetworkTask, "NetworkTask", 8192, (void*)(uintptr_t)wifi_ok, 3, NULL, 0);

    // Core 1: Sensor + FFT (tiempo crítico)
    xTaskCreatePinnedToCore(vSensorTask, "SensorTask", 8192, NULL, configMAX_PRIORITIES - 1, NULL, 1);

    ESP_LOGI(TAG, "Todas las tareas iniciadas correctamente.");
}

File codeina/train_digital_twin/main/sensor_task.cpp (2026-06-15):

#define CONFIG_I2C_SUPPRESS_DEPRECATE_WARN 1
#include "sensor_task.h"
#include "data_types.h"
#include "esp_log.h"
#include "esp_dsp.h"
#include "driver/i2c.h"
#include "driver/gptimer.h"
#include <string.h>
#include <float.h>
#include <math.h>

static const char *TAG = "SENSOR_TASK";

#define SAMPLE_FREQ_HZ 1000 // 1 kHz para el ICM-20948
#define NUM_SAMPLES_PER_FFT FFT_SAMPLES

#define I2C_MASTER_NUM I2C_NUM_0
#define I2C_MASTER_SDA_IO 8
#define I2C_MASTER_SCL_IO 9

static uint8_t s_mpu6050_addr = 0x68;

// === REGISTROS MPU6050 ===
#define MPU6050_ACCEL_XOUT_H 0x3B

static float fft_input[FFT_SAMPLES * 2];
static float fft_window[FFT_SAMPLES];

static esp_err_t mpu6050_write_reg(uint8_t reg, uint8_t data) {
    uint8_t write_buf[2] = {reg, data};
    esp_err_t err = i2c_master_write_to_device(I2C_MASTER_NUM, s_mpu6050_addr, write_buf, sizeof(write_buf), pdMS_TO_TICKS(100));
    if (err != ESP_OK) {
        ESP_LOGE(TAG, "Error escribiendo 0x%02X en registro 0x%02X (I2C error %d)", data, reg, err);
    }
    return err;
}

static esp_err_t mpu6050_read_reg(uint8_t reg, uint8_t *data, size_t len) {
    esp_err_t err = i2c_master_write_read_device(I2C_MASTER_NUM, s_mpu6050_addr, &reg, 1, data, len, pdMS_TO_TICKS(100));
    if (err != ESP_OK) {
        static int fail_count = 0;
        if (fail_count++ % 1000 == 0) ESP_LOGE(TAG, "Error leyendo registro 0x%02X (I2C error %d)", reg, err);
    }
    return err;
}

// Escanea el bus I2C enviando solo el byte de dirección (write de 1 byte a reg 0x00).
// El driver legacy de ESP-IDF no acepta read_size=0, por eso se hace write puro.
// Si el dispositivo ACKa → está presente. Si NACKa → ESP_ERR_TIMEOUT o ESP_FAIL.
static void i2c_scan() {
    ESP_LOGW(TAG, "=== ESCANER I2C (SDA=GPIO%d, SCL=GPIO%d) ===", I2C_MASTER_SDA_IO, I2C_MASTER_SCL_IO);
    int found = 0;
    for (uint8_t addr = 0x08; addr < 0x78; addr++) {
        uint8_t probe = 0x00; // pedimos registro 0x00 sin leer nada después
        i2c_cmd_handle_t cmd = i2c_cmd_link_create();
        i2c_master_start(cmd);
        i2c_master_write_byte(cmd, (addr << 1) | I2C_MASTER_WRITE, true);
        i2c_master_write_byte(cmd, probe, true);
        i2c_master_stop(cmd);
        esp_err_t ret = i2c_master_cmd_begin(I2C_MASTER_NUM, cmd, pdMS_TO_TICKS(10));
        i2c_cmd_link_delete(cmd);
        if (ret == ESP_OK) {
            ESP_LOGW(TAG, "  Dispositivo encontrado en 0x%02X", addr);
            found++;
        }
    }
    if (found == 0) {
        ESP_LOGE(TAG, "  NINGUN dispositivo I2C encontrado. Revisa cableado SDA(GPIO%d)/SCL(GPIO%d) y VCC(3.3V).",
                 I2C_MASTER_SDA_IO, I2C_MASTER_SCL_IO);
    }
    ESP_LOGW(TAG, "=== FIN ESCANER I2C (%d dispositivos) ===", found);
}

static void mpu6050_configure(void) {
    // Salir del modo sleep sin DEVICE_RESET (más seguro para clones)
    // 0x00 = oscilador interno, sleep=0, todos los sistemas activos
    mpu6050_write_reg(0x6B, 0x00);
    vTaskDelay(pdMS_TO_TICKS(50));

    // Deshabilitar FIFO y DMP (User Control)
    mpu6050_write_reg(0x6A, 0x00);
    vTaskDelay(pdMS_TO_TICKS(10));

    // Rango acelerómetro: ±2g → divisor 16384 LSB/g
    mpu6050_write_reg(0x1C, 0x00);
    vTaskDelay(pdMS_TO_TICKS(10));

    // Rango giroscopio: ±250 °/s → divisor 131 LSB/°/s
    mpu6050_write_reg(0x1B, 0x00);
    vTaskDelay(pdMS_TO_TICKS(10));

    // Habilitar todos los ejes (PWR_MGMT_2 = 0x00)
    mpu6050_write_reg(0x6C, 0x00);
    vTaskDelay(pdMS_TO_TICKS(10));
}

static void init_imu_i2c() {
    i2c_config_t conf;
    memset(&conf, 0, sizeof(conf));
    conf.mode = I2C_MODE_MASTER;
    conf.sda_io_num = (gpio_num_t)I2C_MASTER_SDA_IO;
    conf.scl_io_num = (gpio_num_t)I2C_MASTER_SCL_IO;
    conf.sda_pullup_en = GPIO_PULLUP_ENABLE;
    conf.scl_pullup_en = GPIO_PULLUP_ENABLE;
    conf.master.clk_speed = 400000;
    i2c_param_config(I2C_MASTER_NUM, &conf);
    i2c_driver_install(I2C_MASTER_NUM, conf.mode, 0, 0, 0);

    i2c_scan();

    ESP_LOGI(TAG, "Iniciando inicialización IMU...");

    // Configurar en dirección por defecto y leer WHO_AM_I
    mpu6050_configure();
    uint8_t who = 0;
    mpu6050_read_reg(0x75, &who, 1);
    ESP_LOGW(TAG, "WHO_AM_I en 0x%02X = 0x%02X (MPU6050=0x68/0x70, ICM-20948=0xEA)", s_mpu6050_addr, who);

    // Si no hay respuesta útil, probar en 0x69 (AD0=VCC)
    if (who == 0x00) {
        ESP_LOGW(TAG, "Sin respuesta en 0x68, probando 0x69...");
        s_mpu6050_addr = 0x69;
        mpu6050_configure();
        mpu6050_read_reg(0x75, &who, 1);
        ESP_LOGW(TAG, "WHO_AM_I en 0x69 = 0x%02X", who);
        if (who == 0x00) {
            s_mpu6050_addr = 0x68; // restaurar por defecto
            ESP_LOGE(TAG, "Sensor IMU NO encontrado en 0x68 ni 0x69. Revisa SDA/SCL.");
        }
    }

    ESP_LOGI(TAG, "IMU listo en dirección 0x%02X", s_mpu6050_addr);

    // Dump de registros clave para diagnóstico de chip desconocido
    uint8_t regs[8];
    uint8_t start_reg = 0x6B;
    if (mpu6050_read_reg(start_reg, regs, 8) == ESP_OK) {
        ESP_LOGW(TAG, "REG DUMP 0x6B-0x72: %02X %02X %02X %02X %02X %02X %02X %02X",
                 regs[0], regs[1], regs[2], regs[3], regs[4], regs[5], regs[6], regs[7]);
    }
    uint8_t accel_regs[14];
    if (mpu6050_read_reg(0x3B, accel_regs, 14) == ESP_OK) {
        ESP_LOGW(TAG, "REG DUMP 0x3B-0x48 (accel/temp/gyro raw): "
                 "%02X%02X %02X%02X %02X%02X | %02X%02X | %02X%02X %02X%02X %02X%02X",
                 accel_regs[0], accel_regs[1],
                 accel_regs[2], accel_regs[3],
                 accel_regs[4], accel_regs[5],
                 accel_regs[6], accel_regs[7],
                 accel_regs[8], accel_regs[9],
                 accel_regs[10], accel_regs[11],
                 accel_regs[12], accel_regs[13]);
    }
}

static bool IRAM_ATTR timer_isr_handler(gptimer_handle_t timer, const gptimer_alarm_event_data_t *edata, void *user_ctx) {
    TaskHandle_t task = (TaskHandle_t)user_ctx;
    BaseType_t high_task_wakeup = pdFALSE;
    vTaskNotifyGiveFromISR(task, &high_task_wakeup);
    return high_task_wakeup == pdTRUE;
}
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

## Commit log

2026-02-16 Carpeta KiCad
    [GPS.kicad_sch, IMU.kicad_sch, USB_C.kicad_sch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]
2026-05-08 Upgrade tocho
    [GPS.kicad_sch, IMU.kicad_sch, LiPo.kicad_sch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]
2026-05-08 Add dominant_freq to telemetry and backend
    Compute and publish FFT dominant frequency end-to-end: add dominant_freq_hz to TelemetryData_t, compute dominant bin in sensor_task, and include dominant_freq_hz + trainId in MQTT JSON. Network task now skips GPS-without-fix messages and adds configurable WiFi/MQTT/TRAIN_ID macros. Update telemetry_task simulated GPS coords. Backend additions: new mosquitto.conf (listener, allow_anonymous, persistence) and telegraf.conf tuned to store trainId as a tag. Expanded README with setup, flashing, and architecture details.
    [sensor_task.cpp, telemetry_task.cpp]
2026-06-14 cosas sergito
    [partitions.csv]
